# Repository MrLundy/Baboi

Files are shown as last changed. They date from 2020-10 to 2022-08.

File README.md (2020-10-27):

# Baboi
I still have an old printer with a Baboi board, and since efuntime stopped develpment in 2013 I am putting my version here.

I found the version I started with on a forum that isn't there anymore.

https://web.archive.org/web/20160612084530/http://forum.mixshop.com/viewtopic.php?pid=2414

 Reprap firmware based on Sprinter
 Optimize for Sanguinololu 1.2 and above, RAMPS 
 Colin's build V10.1 for Prusa I3 running off of a Baboi Box.
 Chris's modification of Colin's build.

Originally I uploaded version 1.5.5 of my build here.

To compile you will need to use the arduino 1.6.0 DE

Zip file of the latest source:
https://github.com/MrLundy/Baboi/releases

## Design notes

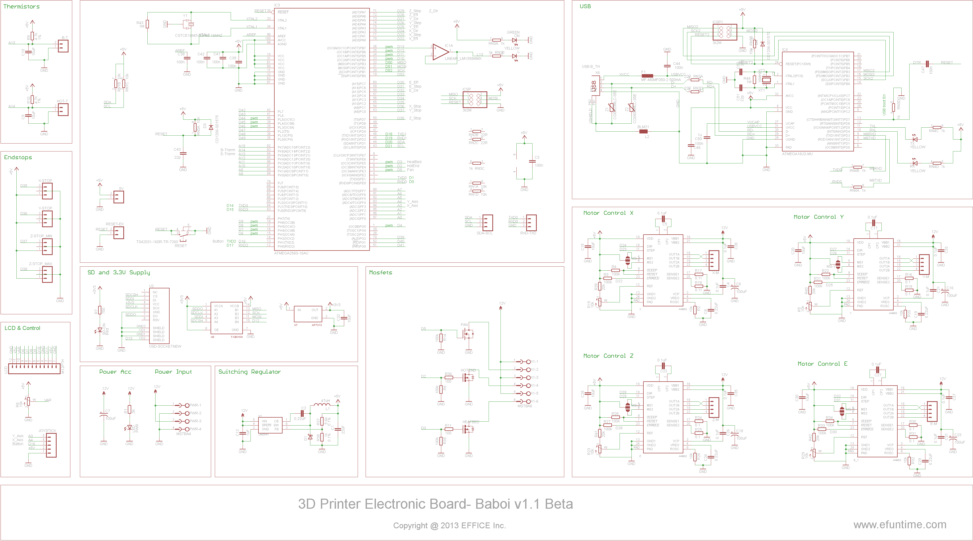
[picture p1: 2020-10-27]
Baboi_schematic.png

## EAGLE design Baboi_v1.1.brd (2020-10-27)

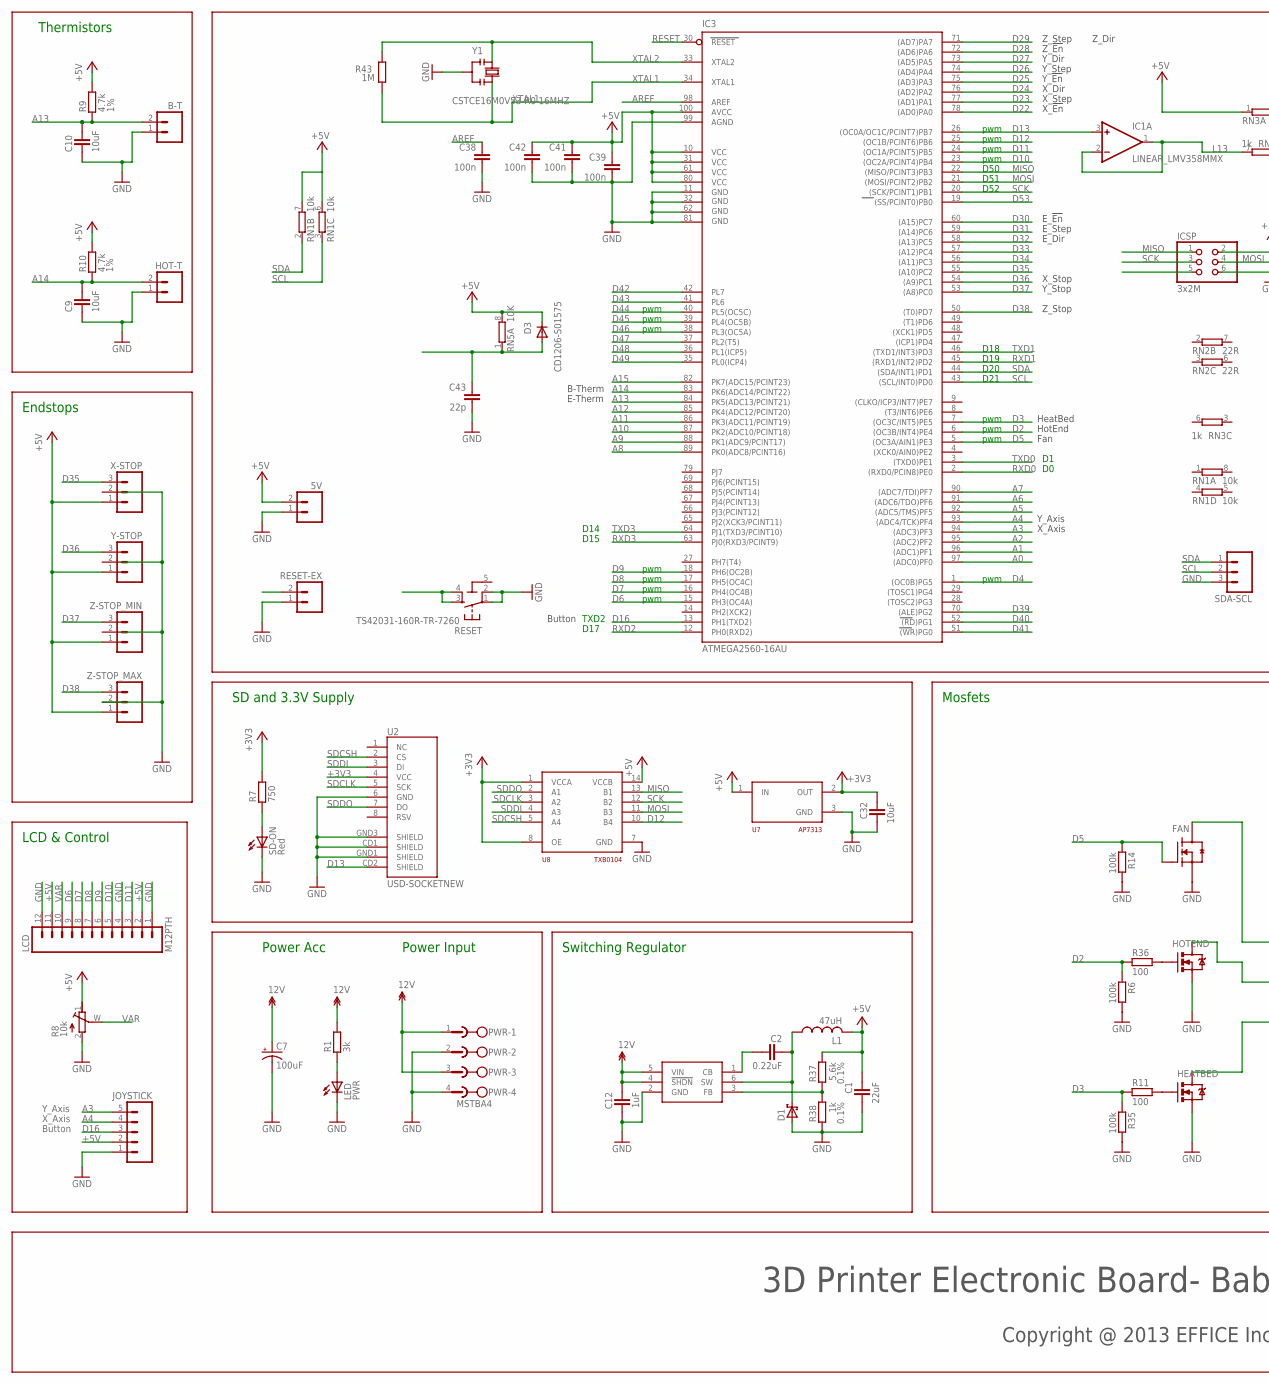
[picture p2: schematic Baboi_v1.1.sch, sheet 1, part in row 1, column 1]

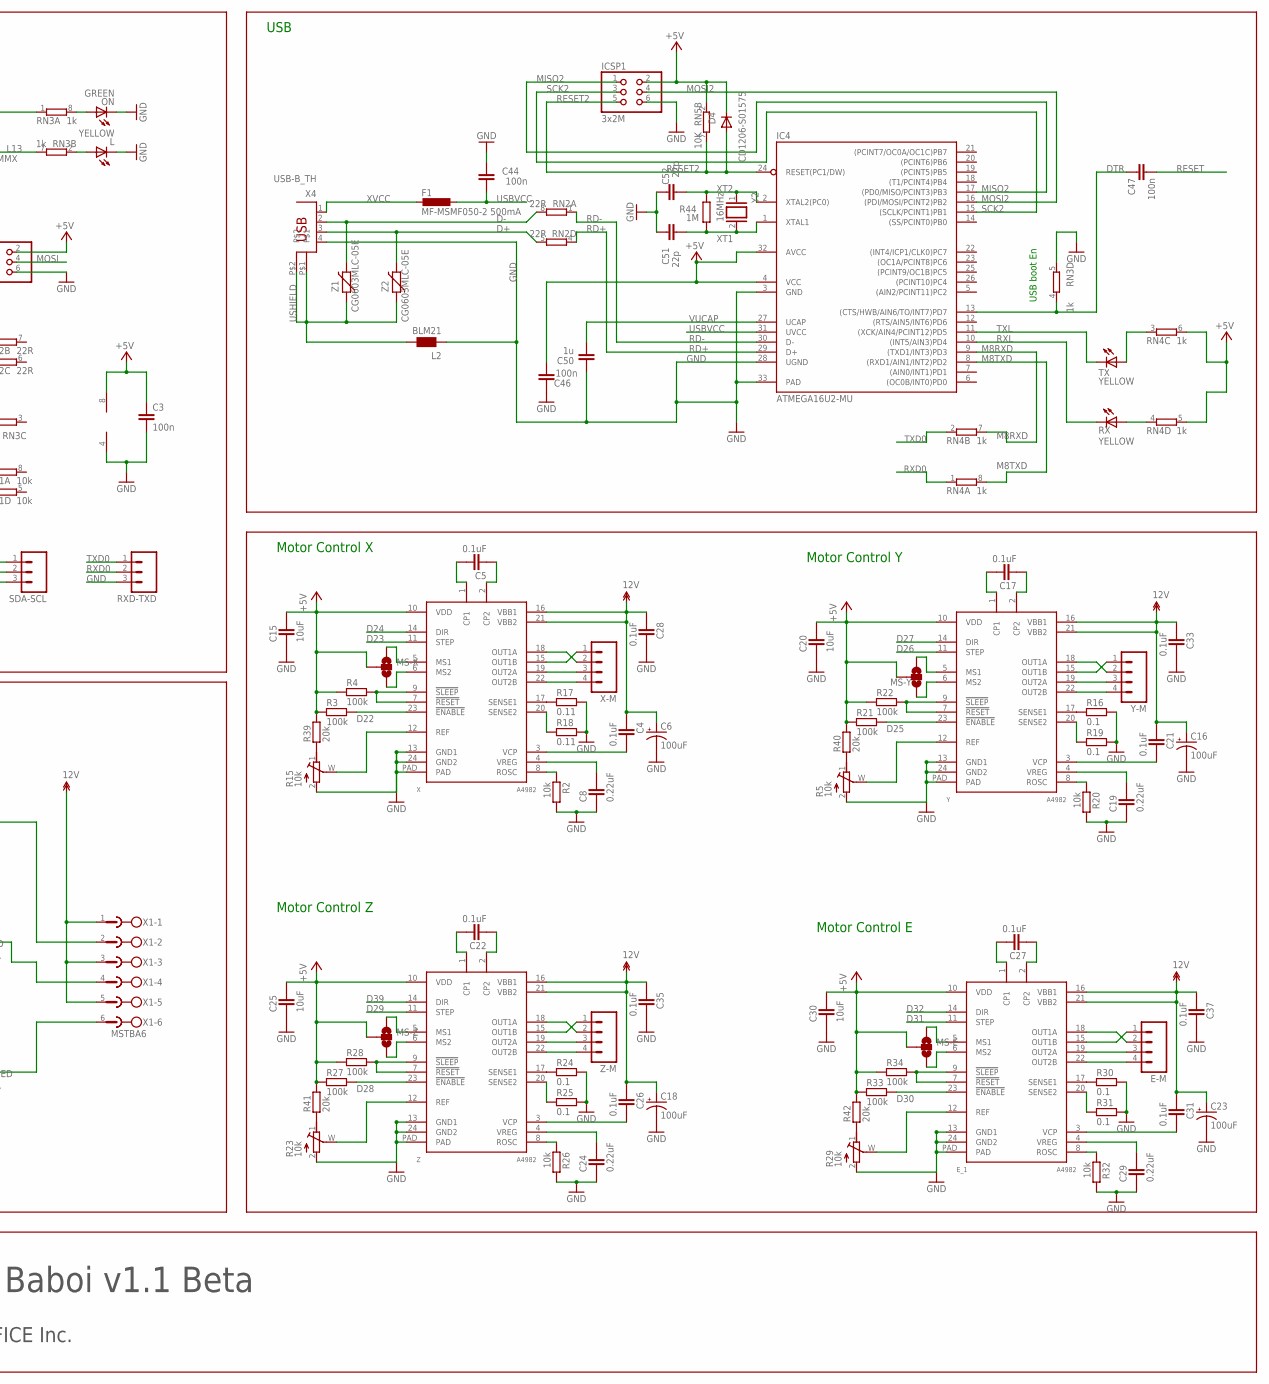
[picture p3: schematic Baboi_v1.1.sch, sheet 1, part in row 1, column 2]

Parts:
5V: M02PTH; 1X02
B-T: M02PTH; 1X02
C1: 22uF; CAPC2012X145AN
C2, C8, C19, C24, C29: 0.22uF; CAPC2012X145AN
C3: 100n; SMARTPRJ_C0603-ROUND
C4, C5, C17, C21, C22, C26, C27, C28, C31, C33, C35, C37: 0.1uF; CAPC2012X145AN
C6, C7, C16, C18, C23: 100uF; PANASONIC_D
C9, C10, C15, C20, C25, C30, C32: 10uF; CAPC2012X145AN
C12: 1uF; CAPC2012X145AN
C38, C39, C41, C42, C44, C46, C47: 100n; C0603-ROUND
C43, C51, C52: 22p; C0603-ROUND
C50: 1u; C0603-ROUND
D1: SCH-DIODESMA; SMA
D3, D4: CD1206-S01575; MINIMELF
E-M: M04PTH; 1X04
E_1: A4982; TSSOP-24
F1: MF-MSMF050-2 500mA; L1812
FAN: RFP30N06LE; SOT95P280X135-3N
HEATBED: RFP30N06LE; TO220V
HOT-T: M02PTH; 1X02
HOTEND: RFP30N06LE; TO220V
IC1: LINEAR_LMV358MMX; LINEAR_MSOP08
IC3: ATMEGA2560-16AU; TQFP100
IC4: ATMEGA16U2-MU; MLF32
ICSP, ICSP1: 3x2M; 2X03
JOYSTICK: M05PTH; 1X05
L: YELLOW; CHIP-LED0805
L1: 47uH; SDR1006
L2: BLM21; 0805
LCD: M12PTH; 1X12
LED: PWR; CHIP-LED0805
MS-E: SOLDERJUMPER_2WAYCONNECTED; SJ_3_CONNECTED
MS-X: SOLDERJUMPER_2WAYCONNECTED; SJ_3_CONNECTED
MS-Y: SOLDERJUMPER_2WAYCONNECTED; SJ_3_CONNECTED
MS-Z: SOLDERJUMPER_2WAYCONNECTED; SJ_3_CONNECTED
ON: GREEN; CHIP-LED0805
PWR: MSTBA4
R1: 3k; RESC2012X70N
R2, R20, R26, R32: 10k; RESC2012X70N
R3, R4, R6, R14, R21, R22, R27, R28, R33, R34, R35: 100k; RESC2012X70N
R5, R8, R15, R23, R29: 10k; RTRIM-ST4ETB
R7: 750; RESC2012X70N
R9, R10: 4.7k; RESC2012X70N; TOLERANCE 1%
R11, R36: 100; RESC2012X70N
R16, R19, R24, R25, R30, R31: 0.1; RESC2012X70N
R17, R18: 0.11; RESC2012X70N
R37: 5.6k; RESC2012X70N; TOLERANCE 0.1%
R38: 1k; RESC2012X70N; TOLERANCE 0.1%
R39, R40, R41, R42: 20k; RESC2012X70N
R43, R44: 1M; R0603-ROUND
RESET: TS42031-160R-TR-7260; TS42
RESET-EX: M02PTH; 1X02
RN1: 10k; RESISTOR-DIL_CAT16
RN2: 22R; CAY16
RN3, RN4: 1k; CAY16
RN5: 10K; CAT16
RX: YELLOW; CHIP-LED0805
RXD-TXD: M03PTH; 1X03
SD-ON: Red; CHIP-LED0805
SDA-SCL: M03PTH; 1X03
TX: YELLOW; CHIP-LED0805
U1: LM2841; TSOT6
U2: USD-SOCKETNEW; MICRO-SD-SOCKET-PP
U7: AP7313; SOT23C
U8: TXB0104; TSSOP14
X: A4982; TSSOP-24
X1: MSTBA6
X4: USB-B_TH; PN61729
X-M: M04PTH; 1X04
X-STOP: M03PTH; 1X03
Y: A4982; TSSOP-24
Y1: CSTCE16M0V53-R0 16MHZ; RESONATOR
Y2: 16MHz; QS
Y-M: M04PTH; 1X04
Y-STOP: M03PTH; 1X03
Z: A4982; TSSOP-24
Z1, Z2: CG0603MLC-05E; CT/CN0603
Z-M: M04PTH; 1X04
Z-STOP_MAX: M03PTH; 1X03
Z-STOP_MIN: M03PTH; 1X03

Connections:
5-GND: RESET.5 (5-GND)
12V: C4.1, C6.+, C7.+, C12.1, C16.+, C18.+, C21.1, C23.+, C26.1, C28.1, C31.1, C33.1, C35.1, C37.1, E_1.16 (VBB1), E_1.21 (VBB2), PWR.1, PWR.3, R1.2, U1.4 (!SHDN), U1.5 (VIN), X.16 (VBB1), X.21 (VBB2), X1.1, X1.3, X1.5, Y.16 (VBB1), Y.21 (VBB2), Z.16 (VBB1), Z.21 (VBB2)
+3V3: C32.1, R7.2, U2.4 (VCC), U7.2 (OUT), U8.1 (VCCA), U8.8 (OE)
+5V: 5V.2, C1.1, C3.1, C15.2, C20.2, C25.2, C30.2, C39.1, C41.1, C42.1, C46.1, D3.C, D4.C, E_1.10 (VDD), IC1.8 (V+), IC3.10 (VCC), IC3.31 (VCC1), IC3.61 (VCC2), IC3.80 (VCC3), IC3.100 (AVCC), IC4.4 (VCC), IC4.32 (AVCC), ICSP.2, ICSP1.2, JOYSTICK.2, L1.P$2 (2), LCD.2, LCD.11, MS-E.2, MS-X.2, MS-Y.2, MS-Z.2, R3.1, R4.1, R8.1 (A), R9.2, R10.2, R21.1, R22.1, R27.1, R28.1, R33.1, R34.1, R37.1, R39.2, R40.2, R41.2, R42.2, RN1.6 (2), RN1.7 (2), RN3.1, RN4.5 (2), RN4.6 (2), RN5.2 (1), RN5.8 (2), U7.1 (IN), U8.14 (VCCB), X.10 (VDD), X-STOP.1, Y.10 (VDD), Y-STOP.1, Z.10 (VDD), Z-STOP_MAX.1, Z-STOP_MIN.1
A0: IC3.97 ((ADC0)PF0)
A1: IC3.96 ((ADC1)PF1)
A2: IC3.95 ((ADC2)PF2)
A3: IC3.94 ((ADC3)PF3), JOYSTICK.5
A4: IC3.93 ((ADC4/TCK)PF4), JOYSTICK.4
A5: IC3.92 ((ADC5/TMS)PF5)
A6: IC3.91 ((ADC6/TDO)PF6)
A7: IC3.90 ((ADC7/TDI)PF7)
A8: IC3.89 (PK0(ADC8/PCINT16))
A9: IC3.88 (PK1(ADC9/PCINT17))
A10: IC3.87 (PK2(ADC10/PCINT18))
A11: IC3.86 (PK3(ADC11/PCINT19))
A12: IC3.85 (PK4(ADC12/PCINT20))
A13: B-T.2, C10.2, IC3.84 (PK5(ADC13/PCINT21)), R9.1
A14: C9.2, HOT-T.2, IC3.83 (PK6(ADC14/PCINT22)), R10.1
A15: IC3.82 (PK7(ADC15/PCINT23))
AREF: C38.1, IC3.98 (AREF)
D2: IC3.6 ((OC3B/INT4)PE4), R6.1, R36.1
D3: IC3.7 ((OC3C/INT5)PE5), R11.1, R35.1
D4: IC3.1 ((OC0B)PG5)
D5: FAN.1 (G), IC3.5 ((OC3A/AIN1)PE3), R14.1
D6: IC3.15 (PH3(OC4A)), LCD.9
D7: IC3.16 (PH4(OC4B)), LCD.8
D8: IC3.17 (PH5(OC4C)), LCD.7
D9: IC3.18 (PH6(OC2B)), LCD.6
D10: IC3.23 ((OC2A/PCINT4)PB4), LCD.5
D11: IC3.24 ((OC1A/PCINT5)PB5), LCD.3
D12: IC3.25 ((OC1B/PCINT6)PB6), U8.10 (B4)
D13: IC1.3 (+IN), IC3.26 ((OC0A/OC1C/PCINT7)PB7), U2.CD2 (SHIELD)
D16: IC3.13 (PH1(TXD2)), JOYSTICK.3
D22: IC3.78 ((AD0)PA0), R3.2, X.23 (!ENABLE)
D23: IC3.77 ((AD1)PA1), X.11 (STEP)
D24: IC3.76 ((AD2)PA2), X.14 (DIR)
D25: IC3.75 ((AD3)PA3), R21.2, Y.23 (!ENABLE)
D26: IC3.74 ((AD4)PA4), Y.11 (STEP)
D27: IC3.73 ((AD5)PA5), Y.14 (DIR)
D28: IC3.72 ((AD6)PA6), R27.2, Z.23 (!ENABLE)
D29: IC3.71 ((AD7)PA7), Z.11 (STEP)
D30: E_1.23 (!ENABLE), IC3.60 ((A15)PC7), R33.2
D31: E_1.11 (STEP), IC3.59 ((A14)PC6)
D32: E_1.14 (DIR), IC3.58 ((A13)PC5)
D33: IC3.57 ((A12)PC4)
D34: IC3.56 ((A11)PC3)
D35: IC3.55 ((A10)PC2), X-STOP.3
D36: IC3.54 ((A9)PC1), Y-STOP.3
D37: IC3.53 ((A8)PC0), Z-STOP_MIN.3
D38: IC3.50 ((T0)PD7), Z-STOP_MAX.3
D39: IC3.70 ((ALE)PG2), Z.14 (DIR)
D40: IC3.52 ((RD)PG1)
D41: IC3.51 ((WR)PG0)
D42: IC3.42 (PL7)
D43: IC3.41 (PL6)
D44: IC3.40 (PL5(OC5C))
D45: IC3.39 (PL4(OC5B))
D46: IC3.38 (PL3(OC5A))
D47: IC3.37 (PL2(T5))
D48: IC3.36 (PL1(ICP5))
D49: IC3.35 (PL0(ICP4))
D53: IC3.19 ((SS/PCINT0)PB0)
D+: RN2.5 (2), X4.3, Z2.2
D-: RN2.8 (2), X4.2, Z1.2
DTR: C47.1, IC4.13 ((CTS/HWB/AIN6/TO/INT7)PD7), RN3.4 (1)
FAN: FAN.3 (D), X1.2
GND: 5V.1, B-T.1, C1.2, C3.2, C6.-, C7.-, C8.1, C9.1, C10.1, C12.2, C15.1, C16.-, C18.-, C19.1, C20.1, C23.-, C24.1, C25.1, C28.2, C29.1, C30.1, C32.2, C33.2, C35.2, C37.2, C38.2, C39.2, C41.2, C42.2, C43.2, C44.2, C46.2, C50.2, C51.2, C52.2, D1.A, E_1.13 (GND1), E_1.24 (GND2), E_1.PAD, FAN.2 (S), HEATBED.3 (S), HOT-T.1, HOTEND.3 (S), IC1.4 (V-), IC3.11 (GND), IC3.32 (GND1), IC3.62 (GND2), IC3.81 (GND3), IC3.99 (AGND), IC4.3 (GND), IC4.28 (UGND), IC4.33 (PAD), ICSP.6, ICSP1.6, JOYSTICK.1, L.C, L2.1, LCD.1, LCD.4, LCD.12, LED.C, ON.C, PWR.2, PWR.4, R2.2, R5.2 (E), R6.2, R8.2 (E), R14.2, R15.2 (E), R16.2, R17.2, R18.2, R19.2, R20.2, R23.2 (E), R24.2, R25.2, R26.2, R29.2 (E), R30.2, R31.2, R32.2, R35.2, R38.2, RESET.1, RESET.2, RESET-EX.1, RN3.5 (2), RXD-TXD.3, SD-ON.C, SDA-SCL.3, U1.2 (GND), U2.6 (GND), U2.CD1 (SHIELD), U2.GND1 (SHIELD), U2.GND3 (SHIELD), U7.3 (GND), U8.7 (GND), X.13 (GND1), X.24 (GND2), X.PAD, X4.4, Y.13 (GND1), Y.24 (GND2), Y.PAD, Y1.2, Z.13 (GND1), Z.24 (GND2), Z.PAD, Z-STOP_MAX.2
HOTBED-GND: HEATBED.2 (D), X1.6
HOTEND-GND: HOTEND.2 (D), X1.4
L13: IC1.1 (OUT), IC1.2 (-IN), RN3.7 (2)
M8RXD: IC4.9 ((TXD1/INT3)PD3), RN4.7 (2)
M8TXD: IC4.8 ((RXD1/AIN1/INT2)PD2), RN4.8 (2)
MISO: IC3.22 ((MISO/PCINT3)PB3), ICSP.1, U8.13 (B1)
MISO2: IC4.17 ((PD0/MISO/PCINT3)PB3), ICSP1.1
MOSI: IC3.21 ((MOSI/PCINT2)PB2), ICSP.4, U8.11 (B3)
MOSI2: IC4.16 ((PDI/MOSI/PCINT2)PB2), ICSP1.4
unnamed: LED.A, R1.1
unnamed: R7.1, SD-ON.A
unnamed: X.19 (OUT2A), X-M.3
unnamed: X.22 (OUT2B), X-M.4
unnamed: Y.19 (OUT2A), Y-M.3
unnamed: Y.22 (OUT2B), Y-M.4
unnamed: HEATBED.1 (G), R11.2
unnamed: R5.1 (A), R40.1
unnamed: Z.19 (OUT2A), Z-M.3
unnamed: X.18 (OUT1A), X-M.2
unnamed: C5.2, X.1 (CP1)
unnamed: C5.1, X.2 (CP2)
unnamed: R2.1, X.8 (ROSC)
unnamed: R17.1, X.17 (SENSE1)
unnamed: R18.1, X.20 (SENSE2)
unnamed: C4.2, X.3 (VCP)
unnamed: X.15 (OUT1B), X-M.1
unnamed: R15.W (S), X.12 (REF)
unnamed: C8.2, X.4 (VREG)
unnamed: Z.22 (OUT2B), Z-M.4
unnamed: R4.2, X.7 (!RESET), X.9 (!SLEEP)
unnamed: R37.2, R38.1, U1.3 (FB)
unnamed: E-M.3, E_1.19 (OUT2A)
unnamed: E-M.4, E_1.22 (OUT2B)
unnamed: Y.15 (OUT1B), Y-M.1
unnamed: MS-X.1, X.5 (MS1)
unnamed: MS-X.3, X.6 (MS2)
unnamed: C17.2, Y.1 (CP1)
unnamed: C17.1, Y.2 (CP2)
unnamed: Y.18 (OUT1A), Y-M.2
unnamed: R19.1, Y.20 (SENSE2)
unnamed: R5.W (S), Y.12 (REF)
unnamed: R20.1, Y.8 (ROSC)
unnamed: C19.2, Y.4 (VREG)
unnamed: R22.2, Y.7 (!RESET), Y.9 (!SLEEP)
unnamed: C21.2, Y.3 (VCP)
unnamed: R16.1, Y.17 (SENSE1)
unnamed: Z.15 (OUT1B), Z-M.1
unnamed: Z.18 (OUT1A), Z-M.2
unnamed: MS-Y.1, Y.5 (MS1)
unnamed: MS-Y.3, Y.6 (MS2)
unnamed: C22.2, Z.1 (CP1)
unnamed: C22.1, Z.2 (CP2)
unnamed: R24.1, Z.17 (SENSE1)
unnamed: R25.1, Z.20 (SENSE2)
unnamed: R23.W (S), Z.12 (REF)
unnamed: R26.1, Z.8 (ROSC)
unnamed: C24.2, Z.4 (VREG)
unnamed: R28.2, Z.7 (!RESET), Z.9 (!SLEEP)
unnamed: C26.2, Z.3 (VCP)
unnamed: E-M.1, E_1.15 (OUT1B)
unnamed: E-M.2, E_1.18 (OUT1A)
unnamed: MS-Z.1, Z.5 (MS1)
unnamed: MS-Z.3, Z.6 (MS2)
unnamed: C27.2, E_1.1 (CP1)
unnamed: C27.1, E_1.2 (CP2)
unnamed: E_1.17 (SENSE1), R30.1
unnamed: E_1.20 (SENSE2), R31.1
unnamed: E_1.12 (REF), R29.W (S)
unnamed: E_1.8 (ROSC), R32.1
unnamed: C29.2, E_1.4 (VREG)
unnamed: E_1.7 (!RESET), E_1.9 (!SLEEP), R34.2
unnamed: C31.2, E_1.3 (VCP)
unnamed: RESET.3, RESET.4
unnamed: R15.1 (A), R39.1
unnamed: ON.A, RN3.8 (2)
unnamed: HOTEND.1 (G), R36.2
unnamed: E_1.5 (MS1), MS-E.1
unnamed: E_1.6 (MS2), MS-E.3
unnamed: R29.1 (A), R42.1
unnamed: C2.1, D1.C, L1.P$1 (1), U1.6 (SW)
unnamed: RN4.4 (1), RX.A
unnamed: C2.2, U1.1 (CB)
unnamed: R23.1 (A), R41.1
unnamed: RN4.3 (1), TX.A
unnamed: L.A, RN3.2 (1)
unnamed: C43.1, D3.A, RN5.1
RD+: IC4.29 (D+), RN2.4 (1)
RD-: IC4.30 (D-), RN2.1
RESET: C47.2, IC3.30 (RESET)
RESET2: D4.A, IC4.24 (RESET(PC1/DW)), ICSP1.5, RN5.7 (2)
RXD0: IC3.2 ((RXD0/PCIN8)PE0), RN4.1, RXD-TXD.2
RXD1: IC3.45 ((RXD1/INT2)PD2)
RXD2: IC3.12 (PH0(RXD2))
RXD3: IC3.63 (PJ0(RXD3/PCINT9))
RXL: IC4.10 ((INT5/AIN3)PD4), RX.C
SCK: IC3.20 ((SCK/PCINT1)PB1), ICSP.3, U8.12 (B2)
SCK2: IC4.15 ((SCLK/PCINT1)PB1), ICSP1.3
SCL: IC3.43 ((SCL/INT0)PD0), RN1.3 (1), SDA-SCL.2
SDA: IC3.44 ((SDA/INT1)PD1), RN1.2 (1), SDA-SCL.1
SDCLK: U2.5 (SCK), U8.3 (A2)
SDCSH: U2.2 (CS), U8.5 (A4)
SDDI: U2.3 (DI), U8.4 (A3)
SDDO: U2.7 (DO), U8.2 (A1)
TXD0: IC3.3 ((TXD0)PE1), RN4.2 (1), RXD-TXD.1
TXD1: IC3.46 ((TXD1/INT3)PD3)
TXD3: IC3.64 (PJ1(TXD3/PCINT10))
TXL: IC4.11 ((XCK/AIN4/PCINT12)PD5), TX.C
USBVCC: C44.1, F1.1, IC4.31 (UVCC)
USHIELD: L2.2, X4.P$1, X4.P$2, Z1.1, Z2.1
VAR: LCD.10, R8.W (S)
VUCAP: C50.1, IC4.27 (UCAP)
XT1: C51.1, IC4.1 (XTAL1), R44.1, Y2.2
XT2: C52.1, IC4.2 (XTAL2(PC0)), R44.2, Y2.1
XTAL1: IC3.34 (XTAL1), R43.1, Y1.3
XTAL2: IC3.33 (XTAL2), R43.2, Y1.1
XVCC: F1.2, X4.1

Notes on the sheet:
Power Acc
Power Input
Switching Regulator
pwm
X_Dir
X_Step
X_!En
Y_Dir
Y_Step
Y_!En
Z_Dir
Z_Step
Z_!En
E_Dir
E_Step
E_!En
E-Therm
B-Therm
Y_Axis
X_Axis
Button
Fan
HotEnd
HeatBed
X_Stop
Y_Stop
Z_Stop
D50
D51
D52
USB boot En
Motor Control X
Motor Control Y
Motor Control Z
Motor Control E
Thermistors
SD and 3.3V Supply
Mosfets
Endstops
USB

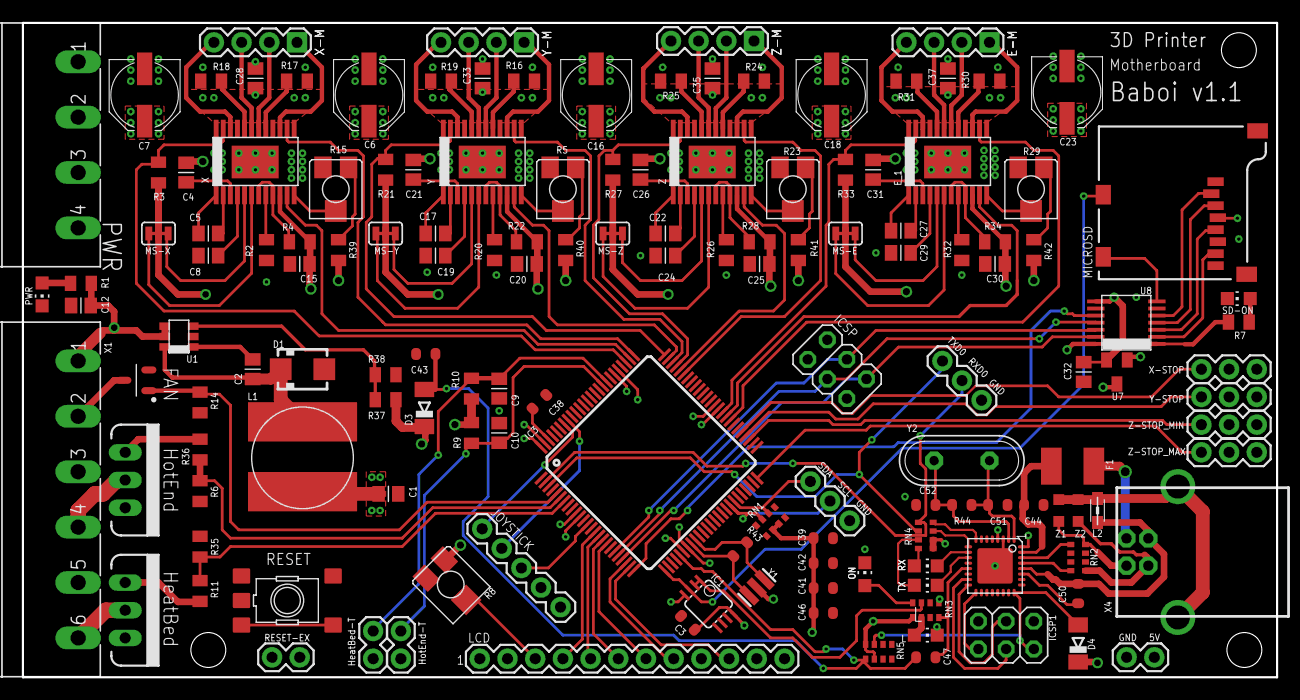
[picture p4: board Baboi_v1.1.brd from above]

Board: 4 copper layers, 115.0 x 60.0 mm, 146 parts (0 on the bottom side), 152 nets.

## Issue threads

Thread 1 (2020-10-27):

Joystick input unreliable

MrLundy, 2020-10-27:
Calibrating the joystick inputs means compiling and pushing new firmware, and after a good calibration it only works for a limited time.

This could be due to a wiring issue changing the resistance through the pins, or some other software bug.

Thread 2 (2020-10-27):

Screen displays garbage after a while

MrLundy, 2020-10-27:
The screen starts scrolling random characters after a long time, or when the wires are wiggled.

Maybe it needs better connections?

Maybe we can reset the screen somehow every so often?

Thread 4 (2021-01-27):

heater timeout while printing

MrLundy, 2021-01-27:
When printing (usually without the sock, or when fan is on full) the hotend stays below the target temperature for too long, and it shut off. The print fails, but octoprint doesn't care.
Trying to fix via PIDs, since I can't find the relevant code in the firmware to change how the timeout works.

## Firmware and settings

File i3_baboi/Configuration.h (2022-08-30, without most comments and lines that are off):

#define CONFIGURATION_H
#define MOTHERBOARD 33
#define THERMISTORHEATER 5
#define THERMISTORBED 7
#define _AXIS_STEP_PER_UNIT {106.6667, 106.6667, 4000, 418.5} //for i3. default mixshop: {106.6667, 106.6667, 4000, 127.4} 143 for MK8 E gear.
#define ENDSTOPPULLUPS // Comment this out (using // at the start of the line) to disable the endstop pullup resistors
const bool X_ENDSTOP_INVERT = false;
const bool Y_ENDSTOP_INVERT = false;
const bool Z_ENDSTOP_INVERT = false;
#define BAUDRATE 115200
#define SDSUPPORT 1
#define SDINITFILE 1
#define USE_ARC_FUNCTION
#define X_ENABLE_ON 0
#define Y_ENABLE_ON 0
#define Z_ENABLE_ON 0
#define E_ENABLE_ON 0
const bool DISABLE_X = false;
const bool DISABLE_Y = false;
const bool DISABLE_Z = true;
const bool DISABLE_E = false;
const bool INVERT_X_DIR = false;
const bool INVERT_Y_DIR = false;
const bool INVERT_Z_DIR = false;
const bool INVERT_E_DIR = false;
#define X_HOME_DIR 1
#define Y_HOME_DIR 1
#define Z_HOME_DIR -1
const bool min_software_endstops = false; //If true, axis won't move to coordinates less than zero.
const bool max_software_endstops = true; //If true, axis won't move to coordinates greater than the defined lengths below.
const int X_MAX_LENGTH = 165;
const int Y_MAX_LENGTH = 220; //225 to 220 to avoid crashing 2022-08-30
const int Z_MAX_LENGTH = 150;
const int NUM_AXIS = 4; // The axis order in all axis related arrays is X, Y, Z, E
#define _MAX_FEEDRATE {200, 200, 3, 60}       // (mm/sec)    set z from 2 to 3 - CL
#define _HOMING_FEEDRATE {2000,2000,100}      // (mm/min) !
#define _AXIS_RELATIVE_MODES {false, false, false, false}
#define MAX_STEP_FREQUENCY 30000 // Max step frequency
#define _ACCELERATION 800         // Axis Normal acceleration mm/s^2
#define _RETRACT_ACCELERATION 2000 // Extruder Normal acceleration mm/s^2
#define _MAX_XY_JERK 8.0
#define _MAX_Z_JERK 0.4
#define _MAX_ACCELERATION_UNITS_PER_SQ_SECOND {1000,1000,50,2500}    // X, Y, Z and E max acceleration in mm/s^2 for printing moves or retracts
#define MINIMUM_PLANNER_SPEED 2.0 // (mm/sec)
#define DEFAULT_MINIMUMFEEDRATE       0.0     // minimum feedrate
#define DEFAULT_MINTRAVELFEEDRATE     0.0
#define SLOWDOWN
const int dropsegments=5; //everything with less than this number of steps will be ignored as move and joined with the next movement
#define _DEF_CHAR_UUID "00000000-0000-0000-0000-000000000000"
  #define BLOCK_BUFFER_SIZE 16
  #define BLOCK_BUFFER_MASK 0x0f
#define MM_PER_ARC_SEGMENT 1
#define N_ARC_CORRECTION 25
#define PIDTEMP 1
#define PID_SOFT_PWM
#define PID_INTEGRAL_DRIVE_MAX 110 // (80) too big, and heater will lag after changing temperature, too small and it might not compensate enough for long-term errors
#define PID_PGAIN 1400 //256 is 1.0  // value of X means that error of 1 degree is changing PWM duty by X, probably no need to go over 25
#define PID_IGAIN 18 //256 is 1.0  // value of X (e.g 0.25) means that each degree error over 1 sec (2 measurements) changes duty cycle by 2X (=0.5) units (verify?)
#define PID_DGAIN 65 //256 is 1.0  // value of X means that around reached setpoint, each degree change over one measurement (half second) adjusts PWM by X units to compensate
#define HEATER_DUTY_FOR_SETPOINT(setpoint) ((int)((120L*(long)setpoint)>>8)-27)  //was 187
#define LED_PWM_FOR_BRIGHTNESS(brightness) ((64*brightness-1384)/(300-brightness))
#define HEATER_CURRENT 255
#define HEATER_CHECK_INTERVAL 200
#define BED_CHECK_INTERVAL 1000
#define DISABLE_CHECK_DURING_ACC
#define DISABLE_CHECK_DURING_TRAVEL 1000
#define MINTEMP 5
#define MAXTEMP 285
#define HEATER_USES_THERMISTOR
#define BED_USES_THERMISTOR
#define CONTROLLERFAN_SEC 60 //How many seconds, after all motors were disabled, the fan should run

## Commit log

2020-10-27 Added Original Schematics
    [Baboi_v1.1.brd, Baboi_v1.1.sch]
2020-10-27 Update README.md
    added arduino 1.6.0 note
2021-01-25 tuning PIDs for stable hotend. Was unable to reach stable temp without sock and failsafing off.
    [Configuration.h]
2021-01-27 after replacing corrupted files, and tuning PIDs
    [Configuration.h]
2022-06-02 Update i3_baboi.ino
    Added M18 (turn motors off) because octoprint doesn't use M84.
2022-08-30 Update Configuration.h
    shortened homing position from y225 to y220 to avoid crashing at y<5mm.
    [Configuration.h]

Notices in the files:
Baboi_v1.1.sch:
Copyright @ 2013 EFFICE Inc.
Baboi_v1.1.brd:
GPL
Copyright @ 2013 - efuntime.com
